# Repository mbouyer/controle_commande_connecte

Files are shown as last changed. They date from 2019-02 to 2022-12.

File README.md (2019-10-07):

# controle_commande_connecte
Une interface controle-commande pilotable par wifi

Le but du projet est de réaliser une interface de commande et contrôle
d'un équipement électrique, avec arrêt automatique lorsque une valeur de
consigne est atteinte, et surveillance à distance par wifi.

L'interface utilisateur est consituée de quatre bouttons poussoir (marche,
arrêt, définition de la consigne par +/-) et un écran LCD pour l'affichage.

Le capteur peut-être un capteur de température (résistance CTN), ou un
capteur de pression avec sortie différentielle.

Le matériel dispose également d'un transormateur de courant permettant de
mesurer l'intensité consomée par la charge. La charge est pilotée à travers
un relais.

* un microchip pic18f25q10,
  auquel sont connectés les capteurs de température et de courant,
  aunsi que les 4 interrupteurs et le relais
* un module ESP8266, qui commandera l'affichage et contient un module
  wifi.

Les deux microcontrolleurs communiquent par un bus i2c et une GPIO.

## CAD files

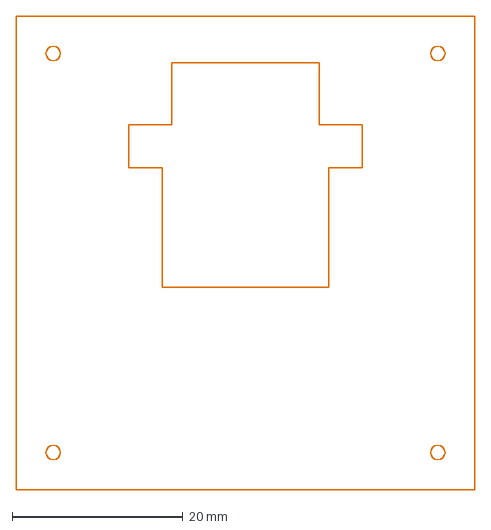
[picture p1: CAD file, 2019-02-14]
hardware/CAD/screen_bottom.dxf
53.7 x 55.4 mm

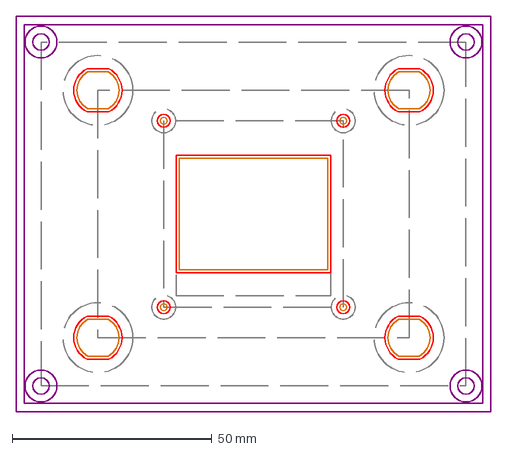
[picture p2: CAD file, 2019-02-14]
hardware/CAD/decoupe_couvercle.dxf
119.0 x 99.0 mm

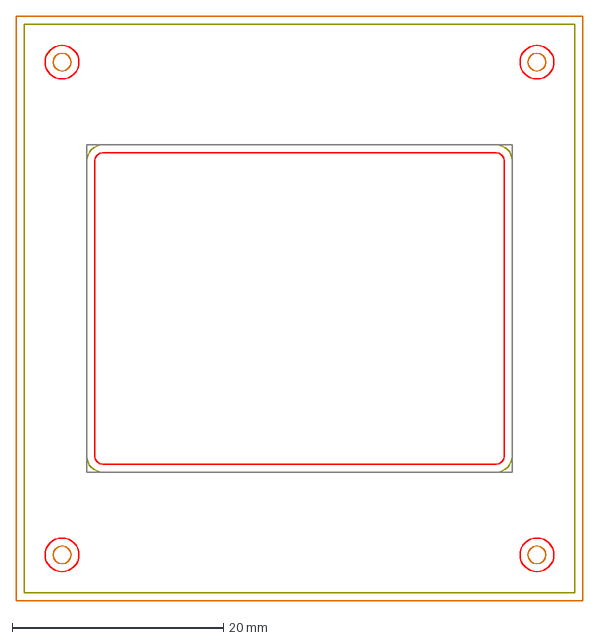
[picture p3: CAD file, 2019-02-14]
hardware/CAD/screen_top.dxf
53.7 x 55.4 mm

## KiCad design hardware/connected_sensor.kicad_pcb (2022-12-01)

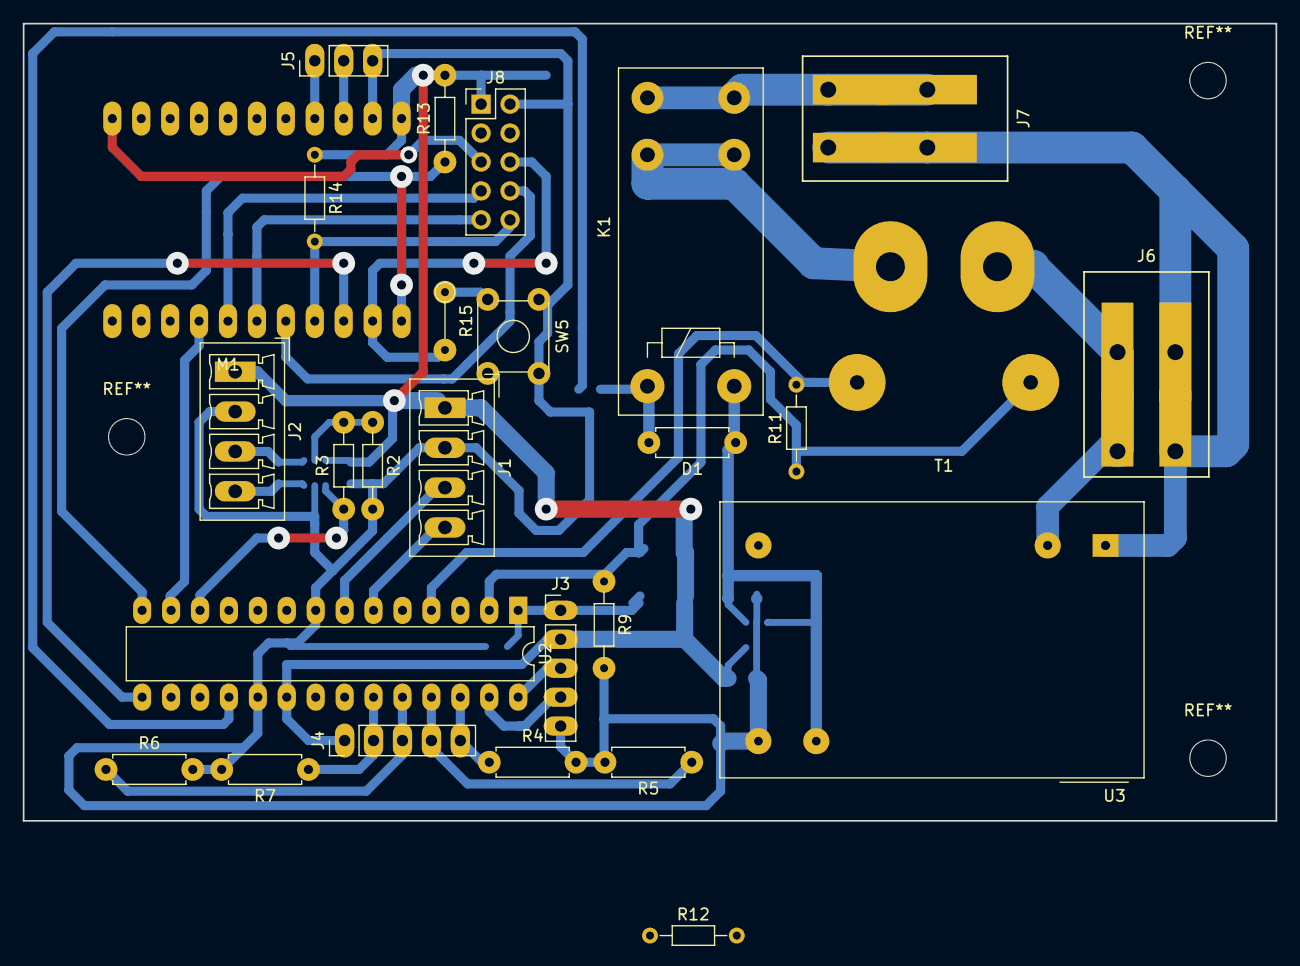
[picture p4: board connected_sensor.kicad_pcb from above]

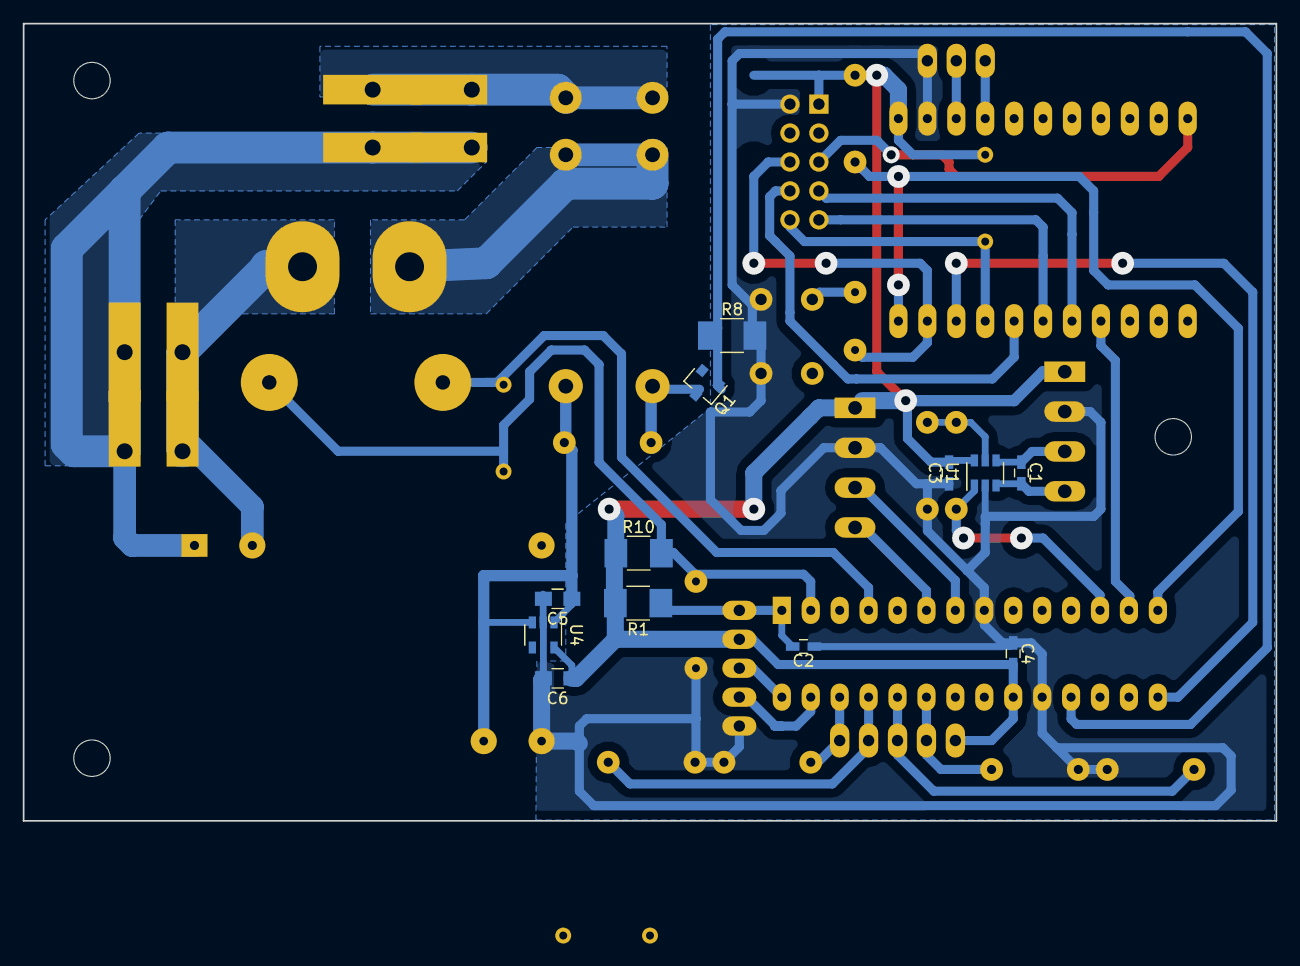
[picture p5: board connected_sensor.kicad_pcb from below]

Board: 2 copper layers, 110.0 x 70.0 mm, 39 parts (12 on the bottom side), 36 nets.

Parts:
C1, C2, C3, C4: 100nF; C_0603_HandSoldering
C5, C6: 1µ; C_0805_HandSoldering
D1: 1N4004; R_Axial_DIN0207_L6.3mm_D2.5mm_P7.62mm_Horizontal
J1, J2: Conn_01x04; PhoenixContact_MCV-G_04x3.50mm_Vertical
J3, J4: Conn_01x05; Pin_Header_Straight_1x05_Pitch2.54mm
J5: Conn_01x03; Pin_Header_Straight_1x03_Pitch2.54mm
J6: AC_IN; 1017491
J7: LOAD; 1017491
J8: UEXT; Pin_Header_Straight_2x05_Pitch2.54mm
K1: G2RL-1A-E 5DC; Relay_SPST_Schrack-RT1-16A-FormA_RM5mm
M1: ESP8266-DEV
Q1: ZXMN3A01FTA; SOT-23
R1, R8: 10K; R_1210_HandSoldering
R2: 5.6K; R_Axial_DIN0204_L3.6mm_D1.6mm_P7.62mm_Horizontal
R3: 100K; R_Axial_DIN0204_L3.6mm_D1.6mm_P7.62mm_Horizontal
R4, R5, R6, R7: 10K; R_Axial_DIN0207_L6.3mm_D2.5mm_P7.62mm_Horizontal
R9: 4.7k; R_Axial_DIN0204_L3.6mm_D1.6mm_P7.62mm_Horizontal
R10: 10k; R_1210_HandSoldering
R11: 18; R_Axial_DIN0204_L3.6mm_D1.6mm_P7.62mm_Horizontal
R12: NA; R_Axial_DIN0204_L3.6mm_D1.6mm_P7.62mm_Horizontal
R13: 2.2K; R_Axial_DIN0204_L3.6mm_D1.6mm_P7.62mm_Horizontal
R14: 47K; R_Axial_DIN0204_L3.6mm_D1.6mm_P7.62mm_Horizontal
R15: 220; R_Axial_DIN0204_L3.6mm_D1.6mm_P5.08mm_Vertical
SW5: SW_Push; SW_TH_Tactile_Omron_B3F-10xx
T1: Transformer_1P_1S; CSE187-LP
U1: MAX4460ESA; SOT-23-6
U2: PIC18F25Q10; DIP-28_W7.62mm_LongPads
U3: IRM-03-5; ACDC-Conv_THTMeanWell-IRM-03-XX
U4: MIC5504-3.3; SOT-23-5

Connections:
+3V3: C3.2, C4.2, C6.1, J1.1, J2.1, J3.2, J4.1, J8.1, M1.1, R1.2, R10.1, R12.2, R13.2, R14.1, U2.20, U4.5
+5V: C5.1, D1.1, K1.A2, U3.16, U4.1, U4.3
/AC1: J6.1, J7.1, U3.1
/AC2: J6.2, T1.1, U3.3
/ACL: J7.2, K1.14
/ACm: K1.11, T1.2
/BT1: J4.2, R7.1, U2.23
/BT2: J4.3, R6.1, U2.24
/BT3: J4.4, R5.1, U2.25
/BT4: J4.5, R4.1, U2.26
/CLK: J8.9, M1.17
/CS: J8.10, M1.19, R14.2
/C_D: J8.6, M1.21, R15.2
/LCD_RST: J8.5, M1.11
/MISO: J8.7, M1.16
/MOSI: J8.8, M1.18
/REL: Q1.1, R8.1, U2.18
/RXD: J5.1, M1.4
/TXD: J5.2, M1.3
CUR_REF: R9.1, R10.2, R11.1, T1.4, U2.2
CUR_SENSE: R11.2, T1.3, U2.4
DATA_READY: M1.15, U2.13
GND: C2.1, C3.1, C4.1, C5.2, C6.2, J1.2, J2.2, J3.5, J5.3, J8.2, M1.2, Q1.2, R2.2, R4.2, R5.2, R6.2, R7.2, R8.2, R9.2, SW5.1, SW5.2, U1.2, U2.8, U2.19, U3.14, U4.2
MCLR: C2.2, J3.1, R1.1, U2.1
unnamed: C1.1, J2.3, U1.6
unnamed: C1.2, J2.4, U1.3
unnamed: D1.2, K1.A1, Q1.3
unnamed: J1.3, U2.7
unnamed: J1.4, U2.6
unnamed: J3.3, U2.28
unnamed: J3.4, U2.27
unnamed: R2.1, R3.2
unnamed: R3.1, U1.1, U2.12
unnamed: R15.1, SW5.3
SCL: M1.22, R13.1, U2.14
SDA: M1.20, R12.1, U2.15

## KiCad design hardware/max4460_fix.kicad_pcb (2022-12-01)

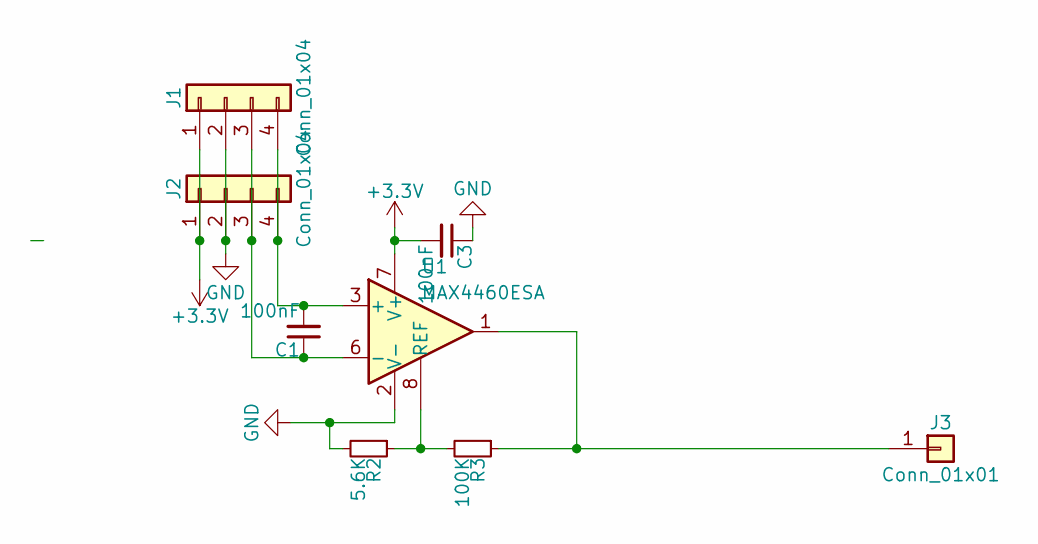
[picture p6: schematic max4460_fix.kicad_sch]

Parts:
C1, C3: 100nF; C_0603_HandSoldering
J1, J2: Conn_01x04; PhoenixContact_MCV-G_04x3.50mm_Vertical
J3: Conn_01x01; Pin_Header_Straight_1x01_Pitch2.54mm
R2: 5.6K; R_Axial_DIN0204_L3.6mm_D1.6mm_P7.62mm_Horizontal
R3: 100K; R_Axial_DIN0204_L3.6mm_D1.6mm_P7.62mm_Horizontal
U1: MAX4460ESA; SOIC-8_3.9x4.9mm_Pitch1.27mm

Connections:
+3V3: C3.2, J1.1, J2.1, U1.7 (V+)
GND: C3.1, J1.2, J2.2, R2.2, U1.2 (V-)
unnamed: C1.1, J1.3, J2.3, U1.6 (-)
unnamed: C1.2, J1.4, J2.4, U1.3 (+)
unnamed: J3.1, R3.1, U1.1
unnamed: R2.1, R3.2, U1.8 (REF)

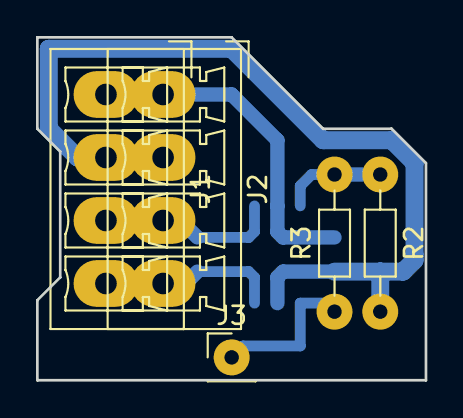
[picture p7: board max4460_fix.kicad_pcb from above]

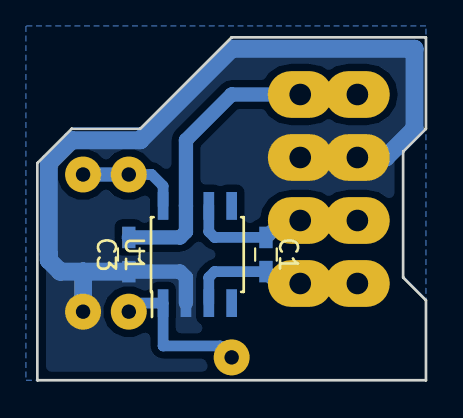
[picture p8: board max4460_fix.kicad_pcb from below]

Board: 2 copper layers, 21.6 x 19.0 mm, 8 parts (3 on the bottom side), 6 nets.

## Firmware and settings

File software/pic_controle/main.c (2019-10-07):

/*
 * Copyright (c) 2019 Manuel Bouyer
 *
 * All rights reserved.
 *
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
 * THIS SOFTWARE IS PROVIDED BY THE NETBSD FOUNDATION, INC. AND CONTRIBUTORS
 * ``AS IS'' AND ANY EXPRESS OR IMPLIED WARRANTIES, INCLUDING, BUT NOT LIMITED
 * TO, THE IMPLIED WARRANTIES OF MERCHANTABILITY AND FITNESS FOR A PARTICULAR
 * PURPOSE ARE DISCLAIMED.  IN NO EVENT SHALL THE FOUNDATION OR CONTRIBUTORS
 * BE LIABLE FOR ANY DIRECT, INDIRECT, INCIDENTAL, SPECIAL, EXEMPLARY, OR
 * CONSEQUENTIAL DAMAGES (INCLUDING, BUT NOT LIMITED TO, PROCUREMENT OF
 * SUBSTITUTE GOODS OR SERVICES; LOSS OF USE, DATA, OR PROFITS; OR BUSINESS
 * INTERRUPTION) HOWEVER CAUSED AND ON ANY THEORY OF LIABILITY, WHETHER IN
 * CONTRACT, STRICT LIABILITY, OR TORT (INCLUDING NEGLIGENCE OR OTHERWISE)
 * ARISING IN ANY WAY OUT OF THE USE OF THIS SOFTWARE, EVEN IF ADVISED OF THE
 * POSSIBILITY OF SUCH DAMAGE.
 */
#include <pic18fregs.h>
#include <stdio.h>
#include <math.h>
#include <my_serial.h>

#define PIC_VERSIONM 0x00
#define PIC_VERSIONm 0x01

extern char stack;
extern char stack_end;
#pragma stack 0x100 256
void _reset (void) __naked __interrupt 0;
void _startup (void) __naked;
static char counter_1hz;	
static volatile short counter_10hz;	
static volatile unsigned char softintrs;
#define INT_10HZ	 (unsigned char)0x01
#define INT_AD		 (unsigned char)0x02
#define INT_I2CFL	 (unsigned char)0x04

#define TIMER0_5MS 192 /* 48 without PLL */

#define TIMER2_10HZ 200

#define CLRWDT __asm__("clrwdt")
#define SLEEP __asm__("sleep")

static unsigned short ad_value;
static unsigned short ad_sense;
static unsigned short ad_ref;
static unsigned char cur_amps;
static unsigned char cur_press;

volatile unsigned char ad_state;
#define ADS_TIMERSTART	(unsigned char)0x01
#define ADS_CURR_REF	(unsigned char)0x02
#define ADS_CURR_SENSE	(unsigned char)0x04
#define ADS_PRESS	(unsigned char)0x08

/* ADC channels */
#define ADC_CUR_REF	0x00
#define ADC_CUR_SENSE	0x02
#define ADC_PRESS	0x11
#define ADC_GND		0x3c  /* 11 1100 */

/*
 * number of samples for current. With a 2Khz timer we'll need 40 samples
 * to capture a full AC cycle. Lets capture 2 cycles. As we do 2 measures
 * per samble this has to be 160
 */
#define ADC_NSMPLSAC	160

/*
 * number of samples for pressures. The ADC is 10 bits, the accumulator
 * is 16, so we can to up to 2^6 = 64 samples.
 */
#define ADC_NSMPLSP	64

/* I2C slave definitions */
#include "i2c.h"
unsigned char i2c_curreg; /* register pointer */
unsigned char i2c_reg_data; /* are we receiving reg pointer or data */
unsigned char i2c_flags; /* current flags */
unsigned char i2c_buttons; /* buttons status */

unsigned char i2cs_a, i2cs_r, i2cs_w, i2cs_s;

#define BUT_START	PORTBbits.RB2
#define BUT_STOP	PORTBbits.RB3
#define BUT_PLUS	PORTBbits.RB5
#define BUT_MINUS	PORTBbits.RB4
unsigned char but_start;
unsigned char but_stop;
unsigned char but_plus;
unsigned char but_minus;

#define OUT_MOTOR	LATCbits.LATC7
#define OUT_DATAR	LATCbits.LATC2

#define PRINTHEX(v) \
	{ \
		unsigned char c = (v); \
		if (c < 10) { \
			putchar('0' + c); \
		} else { \
			putchar(('a' - 10) + c ); \
		} \
	}

void
main(void) __naked
{
	unsigned char c;
	softintrs = 0;
	counter_1hz = 10;	

	/* everything is low priority by default */
	IPR1 = 0;
	IPR2 = 0;
	IPR3 = 0;
	IPR4 = 0;
	IPR5 = 0;
	IPR6 = 0;
	IPR7 = 0;
	INTCON = 0;
	INTCONbits.IPEN=1; /* enable interrupt priority */
	
	/* setup ADC and analog inputs */
	ANSELB=0x00; /* port B all digital */
	ANSELC = 0x01; //Set RC1 to analog, others digital
	TRISCbits.TRISC1 = 1;
	ANSELA = 0x05; //Set RA0 & RA2 to analog, others digital
	TRISAbits.TRISA0 = 1;
	TRISAbits.TRISA2 = 1;

	ADCON0 = 0;
	ADCON1 = 0;
	ADCON2 = 0x01; /* accumulate mode */
	ADCON0bits.ADFM = 1; /* right justify */
	ADCON0bits.ADON = 1;
	ADCLK=0x2e; /* Fosc / 64, 1us */
	ADACQ=10; /* 10us aquisition */
	ADREF=0;
	PIR1bits.ADIF = 0;
	PIE1bits.ADIE = 0;

	FVRCON = 0x82; /* fvr on, ADC output 2.048v */

	/* configure timer0 as free-running counter at 62.5Khz */
	T0CON0 = 0x10; /* 16bits, 1:1 postscaler */
	T0CON1 = 0x48; /* F0sc/4, 1:256 prescaler */
	PIR0bits.TMR0IF = 0;
	PIE0bits.TMR0IE = 0; /* no interrupt */
	T0CON0bits.T0EN = 1;
	
	USART_INIT(0);
	stdout = STREAM_USER; /* Use the macro PUTCHAR with printf */

#if TIMER2_10HZ == 100
	/* configure timer2 for 1Khz interrupt */
	T2CON = 0x64; /* postscaller 1/5, prescaler 1/64 */
	PR2 = 200; /* 1khz output */
#elif TIMER2_10HZ == 200
	/* configure timer2 for 1Khz interrupt */
	T2CON = 0x64; /* postscaller 1/5, prescaler 1/64 */
	PR2 = 100; /* 2khz output */
#else
#error "unknown TIMER2_10HZ"
#endif
	T2CLK = 0x02; /* Fosc */
	counter_10hz = TIMER2_10HZ;
	T2CONbits.TMR2ON = 1;
	PIR4bits.TMR2IF = 0;
	IPR4bits.TMR2IP = 1; /* high priority interrupt */
	PIE4bits.TMR2IE = 1;


	/* configure i2c */
	SSP1CON1 = 0x16; /* enable i2c in slave mode, 7 bit adress, CKP */
	SSP1CON2 = 0x01; /* SEN */
	SSP1CON3 = 0x00;
	SSP1STAT = 0x80;
	SSP1ADD = (I2C_ADDRESS << 1) & 0xfe;
	// SSP1MSK = 0xfe;
	SSP1MSK = 0x00;
	TRISCbits.TRISC3 = 1;
	TRISCbits.TRISC4 = 1;
	RC3PPS=0x0D;
	RC4PPS=0x0E;
	SSP1CON1bits.SSPEN=1;
	PIR3bits.SSP1IF = 0; // waiting to transmit/receive
	PIE3bits.SSP1IE = 1; // synchronous serial port interrupt enable
	i2c_curreg = i2c_flags = i2c_buttons = 0;
	but_start = but_stop = but_plus = but_minus = 0;
	i2cs_a = i2cs_r = i2cs_w = i2cs_s = 0;

	ad_state = ADS_PRESS;
	cur_amps = cur_press = 0;

	INTCONbits.GIE_GIEH=1;  /* enable high-priority interrupts */
	INTCONbits.PEIE_GIEL=1; /* enable low-priority interrrupts */

	OUT_MOTOR = 0; 
	TRISCbits.TRISC7 = 0;

	/* 4 buttons */
	TRISBbits.TRISB2 = 1;
	TRISBbits.TRISB3 = 1;
	TRISBbits.TRISB4 = 1;
	TRISBbits.TRISB5 = 1;

	OUT_DATAR = 0;
	TRISCbits.TRISC2 = 0; /* data_ready = out */

	WDTCON0bits.WDTPS = 0x0b; /* 2s watchdog */
	WDTCON1 = 0x17; /* MFINTOSC, always open */
	WDTCON0bits.SWDTEN = 1;
	CPUDOZEbits.IDLEN = 1;

	printf("ready %d.%d\n", PIC_VERSIONM, PIC_VERSIONm);

again:
	while (1) {
		CLRWDT;
		if (softintrs & INT_I2CFL) {
			softintrs &= ~INT_I2CFL;
			if (i2c_flags & I2C_FLAGS_MOTOR)
				OUT_MOTOR = 1;
			else
				OUT_MOTOR = 0;
		}
		if (softintrs & INT_AD) {
			if (ad_state & ADS_PRESS) {
				ad_value = (ADACCH << 8) | ADACCL;
				cur_press = (float)ad_value * 0.4531398 /
				    (float)ADC_NSMPLSP;
			} else {
				cur_amps = (float)ad_value * 0.61666667 /
				    (float)(ADC_NSMPLSAC / 2);
			}
			softintrs &= ~INT_AD;
		}
		if (softintrs & INT_10HZ) {
			softintrs &= ~INT_10HZ;
			/* cleanup hardware, in case something didn't complete */
			ADCON0bits.ADGO = 0;
			PIE1bits.ADIE = 0;
			ADCON2bits.ADACLR = 1;
			while (ADCON2bits.ADACLR)
				; /* wait */
			if ((ad_state & ADS_PRESS) != 0) {
				ad_value = 0;
				ADPCH = ADC_GND;
				ADPCH = ADC_CUR_REF;
				ADREF = 0x03; /* FVR */
				ad_state = ADS_CURR_REF;
			} else {
				ADPCH = ADC_GND;
				ADPCH = ADC_PRESS;
				ADREF = 0x00; /* Vcc */
				ad_state = ADS_PRESS;
			}
			PIR1bits.ADIF = 0;
			PIE1bits.ADIE = 1;
			ad_state |= ADS_TIMERSTART;
			counter_1hz--;
			if (counter_1hz == 0) {
				counter_1hz = 10;
				printf("I %d P %d B %d\n", cur_amps, cur_press, i2c_buttons);
				printf("i2c a %d r %d w %d s %d\n",
				    i2cs_a, i2cs_r, i2cs_w, i2cs_s);
				i2cs_a = i2cs_r = i2cs_w = i2cs_s = 0;
			}
		}
		if (but_start == 0xff)
			i2c_buttons |= I2C_BUTTONS_START;
		else if (but_start == 0)
			i2c_buttons &= ~I2C_BUTTONS_START;
		if (but_stop == 0xff)
			i2c_buttons |= I2C_BUTTONS_STOP;
		else if (but_stop == 0)
			i2c_buttons &= ~I2C_BUTTONS_STOP;
		if (but_plus == 0xff)
			i2c_buttons |= I2C_BUTTONS_PLUS;
		else if (but_plus == 0)
			i2c_buttons &= ~I2C_BUTTONS_PLUS;
		if (but_minus == 0xff)
			i2c_buttons |= I2C_BUTTONS_MINUS;
		else if (but_minus == 0)
			i2c_buttons &= ~I2C_BUTTONS_MINUS;

		if (RCREG1 == 'r')
			break;
		SLEEP;
	}

end:

	while ((c = getchar()) != 'r') {
		printf("got %c\n", c);
		goto again;
	}
	printf("returning\n");
	while (PIE3bits.TX1IE); /* wait for transmit to complete */
	

	INTCONbits.PEIE=0; /* disable peripheral interrupts */
	INTCONbits.GIE=0;  /* disable interrrupts */
}
unsigned int timer0_read() __naked
{
	/* return TMR0L | (TMR0H << 8), reading TMR0L first */
	__asm
	movf    _TMR0L, w
	movff   _TMR0H, _PRODL
	return
	__endasm;
}

/* Vectors */
void _reset (void) __naked __interrupt 0
{
	__asm__("goto __startup");
}

void _startup (void) __naked
{
  __asm
    // Initialize the stack pointer
    lfsr 1, _stack_end
    lfsr 2, _stack_end
    clrf _TBLPTRU, 0    // 1st silicon doesn't do this on POR

    __endasm ;

  /* Call the user's main routine */
  main();
  __asm__("reset");
}

/*
 * high priority interrupt. Split in 2 parts; one for the entry point
 * where we'll deal with timer0, then jump to another address
 * as we don't have enough space before the low priority vector
 */
void _irqh (void) __naked __shadowregs __interrupt 1
{
	__asm
	goto _irqh_timer2
	__endasm ;

}

void irqh_timer2(void) __naked
{
	/*
	 * no sdcc registers are automatically saved,
	 * so we have to be carefull with C code !
	 */
	__asm
	MOVFF   r0x00, POSTDEC1
	__endasm;
	PIR4bits.TMR2IF = 0;
	counter_10hz--;
	if (counter_10hz == 0) {
		counter_10hz = TIMER2_10HZ;
		softintrs |= INT_10HZ;
	}

	if (ADCON0bits.ADGO == 0 && (ad_state & ADS_TIMERSTART)) {
		ADCON0bits.ADGO = 1;
		ad_state &= ~ADS_TIMERSTART;
	}

	if (BUT_START) {
		if (but_start == 0x7f)
			OUT_DATAR = 1;
		but_start = but_start << 1;
		but_start |= (unsigned char)0x01;
	} else {
		if (but_start == 0x80)
			OUT_DATAR = 1;
		but_start = but_start << 1;
	}

	if (BUT_STOP) {
		if (but_stop == 0x7f)
			OUT_DATAR = 1;
		but_stop = but_stop << 1;
		but_stop |= (unsigned char)0x01;
	} else {
		if (but_stop == 0x80)
			OUT_DATAR = 1;
		but_stop = but_stop << 1;
	}

	if (BUT_PLUS) {
		if (but_plus == 0x7f)
			OUT_DATAR = 1;
		but_plus = but_plus << 1;
		but_plus |= (unsigned char)0x01;
	} else {
		if (but_plus == 0x80)
			OUT_DATAR = 1;
		but_plus = but_plus << 1;
	}

	if (BUT_MINUS) {
		if (but_minus == 0x7f)
			OUT_DATAR = 1;
		but_minus = but_minus << 1;
		but_minus |= (unsigned char)0x01;
	} else {
		if (but_minus == 0x80)
			OUT_DATAR = 1;
		but_minus = but_minus << 1;
	}

	__asm
	MOVFF   PREINC1, r0x00
	retfie 1
	nop
	__endasm;
}

void _irq (void) __interrupt 2 /* low priority */
{
	USART_INTR;

	if (PIR1bits.ADIF && PIE1bits.ADIE) {
		PIR1bits.ADIF = 0;
		if (ad_state & ADS_PRESS) {
			if (ADCNT == ADC_NSMPLSP) {
				softintrs |= INT_AD;
				PIE1bits.ADIE = 0;
			} else {
				ad_state |= ADS_TIMERSTART;
			}
		} else {
			if (ADCNT == ADC_NSMPLSAC) {
				softintrs |= INT_AD;
				PIE1bits.ADIE = 0;
			} else {
				if (ad_state & ADS_CURR_REF) {
					ad_ref = (ADRESH << 8) | ADRESL;
					ad_state = ADS_CURR_SENSE;
					ADPCH = ADC_GND;
					ADPCH = ADC_CUR_SENSE;
					ADCON0bits.ADGO = 1;
				} else {
					ad_sense = (ADRESH << 8) | ADRESL;
					if (ad_sense < ad_ref) {
						ad_value+= (ad_ref - ad_sense);
					} else {
						ad_value+= (ad_sense - ad_ref);
					}
					ad_state = ADS_CURR_REF;
					ADPCH = ADC_GND;
					ADPCH = ADC_CUR_REF;
					ad_state |= ADS_TIMERSTART;
				}
			}
		}
	}

	if (PIR3bits.SSP1IF == 1) {
		PIR3bits.SSP1IF = 0;
		if (!SSP1CON3bits.ACKTIM) {
			if ((SSP1CON1bits.SSPOV) || (SSP1CON1bits.WCOL)) {
				printf("i2c o %d\n", SSP1CON1);
				SSP1CON1bits.SSPOV = 0;
				SSP1CON1bits.WCOL = 0;
				SSP1CON1bits.CKP = 1;
				(void)SSP1BUF; /* clear buffer */
			}

			if (!SSP1STATbits.D_NOT_A && SSP1STATbits.BF) {
				// printf("i2c a %d\n", SSP1BUF);
				i2cs_a++;
				(void)SSP1BUF;
				i2c_reg_data = 1;
			}  else if (!SSP1STATbits.R_NOT_W && SSP1STATbits.BF) {
				if (i2c_reg_data) {
					i2c_curreg = SSP1BUF;
					//printf("i2c s %d\n", i2c_curreg);
					i2c_reg_data = 0;
					i2cs_s++;
				} else {
					// printf("i2c w %d\n", i2c_curreg);
					i2cs_w++;
					switch(i2c_curreg) {
					case I2C_R_FLAGS:
						i2c_flags = SSP1BUF;
						softintrs |= INT_I2CFL;
						break;
					default:
						(void)SSP1BUF;
						break;
					}
					i2c_curreg++;
				}
			}

			if (SSP1STATbits.R_NOT_W) {
				(void)SSP1BUF;
				// printf("i2c r %d\n", i2c_curreg);
				i2cs_r++;
				switch(i2c_curreg) {
				case I2C_R_VERSM:
					SSP1BUF = PIC_VERSIONM;
					break;
				case I2C_R_VERSm:
					SSP1BUF = PIC_VERSIONm;
					break;
				case I2C_R_FLAGS:
					SSP1BUF = i2c_flags;
					break;
				case I2C_R_BUTTONS:
					SSP1BUF = i2c_buttons;
					OUT_DATAR = 0;
					break;
				case I2C_R_AMP:
					SSP1BUF = cur_amps;
					break;
				case I2C_R_PRES:
					SSP1BUF = cur_press;
					break;
				default:
					SSP1BUF = 0;
					break;
				}
				i2c_curreg++;
			}
		}
		SSP1CON1bits.CKP = 1;
	}
}

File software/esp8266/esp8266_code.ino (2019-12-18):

/*
 * Copyright (c) 2019 Manuel BOUYER
 * All rights reserved.
 *
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
 * THIS SOFTWARE IS PROVIDED BY THE NETBSD FOUNDATION, INC. AND CONTRIBUTORS
 * ``AS IS'' AND ANY EXPRESS OR IMPLIED WARRANTIES, INCLUDING, BUT NOT LIMITED
 * TO, THE IMPLIED WARRANTIES OF MERCHANTABILITY AND FITNESS FOR A PARTICULAR
 * PURPOSE ARE DISCLAIMED.  IN NO EVENT SHALL THE FOUNDATION OR CONTRIBUTORS
 * BE LIABLE FOR ANY DIRECT, INDIRECT, INCIDENTAL, SPECIAL, EXEMPLARY, OR
 * CONSEQUENTIAL DAMAGES (INCLUDING, BUT NOT LIMITED TO, PROCUREMENT OF
 * SUBSTITUTE GOODS OR SERVICES; LOSS OF USE, DATA, OR PROFITS; OR BUSINESS
 * INTERRUPTION) HOWEVER CAUSED AND ON ANY THEORY OF LIABILITY, WHETHER IN
 * CONTRACT, STRICT LIABILITY, OR TORT (INCLUDING NEGLIGENCE OR OTHERWISE)
 * ARISING IN ANY WAY OUT OF THE USE OF THIS SOFTWARE, EVEN IF ADVISED OF THE
 * POSSIBILITY OF SUCH DAMAGE.
 */

#include <ESP8266WiFi.h>
#include <ESPAsyncTCP.h>
#include <ESPAsyncWebServer.h>
#include <DNSServer.h>
#include <LCD_3310.h>
#include <Wire.h>
#include <FS.h>
#include <ESP_EEPROM.h>
#include "../pic_controle/i2c.h"
#include "wifi_params.h"

#define SDA_PIN 2
#define SCL_PIN 4
#define DATA_READY  16

#define VERSIONM 0
#define VERSIONm 3

#define EEPROM_VERSION 0x01
#define EEPROM_SIZE 16 // overkill but minimum is 16

// #define NO_PIC 1 // emulation mode

#ifdef NO_PIC
unsigned long no_pic_emultime = 0;
#define NO_PIC_UPDATE 20000 // 20s
float no_pic_press;
#endif

unsigned short runtime;
unsigned int milliruntime;
unsigned long runtime_last;

#define DISP_UPDATE 500 //ms
unsigned long disp_up_last = 0;

// motor status
bool motor_on = 0;

// sensors
unsigned char press;
unsigned char target_press = 115;
unsigned int current;

// ETA compute
#define ETA_SAMPLES 5
unsigned char previous_press[ETA_SAMPLES];
unsigned long eta_millis;
short etatime;


// buttons
unsigned char buttons_state;
unsigned long plusminus_timer;
#define PLUSMINUS_SLOW 1000 // 1s
#define PLUSMINUS_FAST 3000 // 3s

// Access Point

const IPAddress local_IP(192,168,1,1);
const IPAddress subnet(255,255,255,0);

AsyncWebServer server(80);
DNSServer dnsServer;

static int
i2c_write(char reg, char value)
{
	Wire.beginTransmission(I2C_ADDRESS);
	Wire.write(reg);
	Wire.write(value);
	return Wire.endTransmission();
	// 0:success
	// 1:data too long to fit in transmit buffer
	// 2:received NACK on transmit of address
	// 3:received NACK on transmit of data
	// 4:other error
}

static int
i2c_read(char reg, char *v, char count)
{
	int ret;
	int i;

	Wire.beginTransmission(I2C_ADDRESS);
	Wire.write(reg);
	ret = Wire.endTransmission();
	if (ret != 0)
		return -ret;

	Wire.requestFrom(I2C_ADDRESS, count);
	ret = Wire.available();
	for (i = 0; i < ret; i++) {
		v[i] = Wire.read();
	}
	return ret;
}

static void
do_motor(bool m)
{
	unsigned char flags = 0;
	int ret;
	char buf[17];

	motor_on = m;
	if (motor_on)
		flags |= I2C_FLAGS_MOTOR;

#ifndef NO_PIC
	while ((ret = i2c_write(I2C_W_FLAGS, flags)) != 0) {
		LCDClear();
		sprintf(buf, "write pic %d", ret);
		Serial.println(buf);
		LCDStr(5, 2, buf, 0, 5); 
		delay(500);
	}
#endif
}

static void
time2str(char *buf, int time) {
	sprintf(buf, "%dh%02d", time / 60, time % 60);
}

static void
etatime2str(char *buf) {
	if (etatime == 0) {
	    sprintf(buf, "----");
	} else if (etatime >= 60 * 10) {
	    sprintf(buf, "++++");
	} else {
	    time2str(buf, etatime);
	}
}


static String
toStringIp(IPAddress ip) {
	String res = "";
	for (int i = 0; i < 3; i++) {
		res += String((ip >> (8 * i)) & 0xFF) + ".";
	}
	res += String(((ip >> 8 * 3)) & 0xFF);
	return res;
}

static String
getContentType(String filename) {
	if(filename.endsWith(".html")) return "text/html";
	else if(filename.endsWith(".css")) return "text/css";
	else if(filename.endsWith(".js")) return "application/javascript";
	else if(filename.endsWith(".png")) return "image/png";
	else if(filename.endsWith(".gif")) return "image/gif";
	else if(filename.endsWith(".jpg")) return "image/jpeg";
	else if(filename.endsWith(".ico")) return "image/x-icon";
	else if(filename.endsWith(".xml")) return "text/xml";
	return "text/plain";
}



static void
handleNotFound(AsyncWebServerRequest *request)
{
	String filename = "/http" + request->url();

	if(SPIFFS.exists(filename)) {
		request->send(SPIFFS, filename, getContentType(filename));
		return;
	}
	Serial.print("request for http://");
	Serial.print(request->host());
	Serial.println(request->url());
	request->redirect(String("http://") + toStringIp(local_IP));
}

String
fill_html(const String& var)
{
	char buf[10];
	if(var == "PRESS") {
		return String(press*2);
	} else if (var == "CONS") {
		return String(target_press*2);
	} else if (var == "AMPS") {
		sprintf(buf, "%d.%d", current / 10, current % 10);
		return String(buf);
	}
	Serial.print("unknown HTML tag ");
	Serial.println(var);
	return String("");
}


void
setup() {
	char v[2];
	char buf[80];
	int ret, i;
	char ee_version;

	delay(1000);
	Serial.begin(57600);
	Serial.println();
	Serial.println("Configuring access point...");
	WiFi.softAP(WIFI_SSID, WIFI_PASS, 1, false, 8);
	WiFi.softAPConfig(local_IP, local_IP, subnet);

	Serial.print("AP IP address: ");
	Serial.println(local_IP);

	/* Setup the DNS server redirecting all the domains to the apIP */
	dnsServer.setTTL(300);
	dnsServer.setErrorReplyCode(DNSReplyCode::NoError);
	dnsServer.start(53, "*", local_IP);


	Wire.begin(SDA_PIN,SCL_PIN);
	Wire.setClock(100000); // clock 100KHz
	pinMode(16, INPUT);  // Data_ready

	LCDInit();
	LCDContrast (0x60);
	LCDClear();
	LCDUpdate();

	sprintf(buf, "aperosafe %d.%d", VERSIONM, VERSIONm);
	Serial.println("wait on PIC");
	LCDStr(5, 2, "wait on pic", 0, 5);
#ifndef NO_PIC
	while ((ret = i2c_read(I2C_R_VERSM, v, 2)) != 2) {
		sprintf(buf, "wait on pic %d", ret);
		Serial.println(buf);
		delay(500);
	}
	if (v[0] != PIC_VERSIONM) {
		sprintf(buf, "wrong pic %d.%d", v[0], v[1]);
		LCDStr(5, 2, buf, 0, 5); 
		Serial.println(buf);
		while (1) {
			delay(500);
		}
	}
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

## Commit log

2018-12-12 Premier import, le matériel devrait être définitif
    [connected_sensor.kicad_pcb, connected_sensor.sch]
2019-01-10 max4460esa est SIOC8 et pas SOT-6; ajout d'un petit PCB d'adaptation. Il se soude sur les broches résistances et connecteur (J2) du PCB principal.
    [max4460_fix.kicad_pcb, max4460_fix.sch]
2019-02-14 Ajout des fichiers CAO pour les découpes et support écran.
    [decoupe_couvercle.dxf, screen_bottom.dxf, screen_top.dxf]
2019-10-07 L'ecran necessite 2 GPIOs en plus du SPI. Re-route 2 GPIOs de l'ESP vers le connecteur ecran.
    [connected_sensor.kicad_pcb, connected_sensor.sch]
2019-10-07 Version initiale du logiciel pour les microcontrolleurs.
2019-10-17 Serve any file present in SPIFFS, with content-type based on extention. Provide sensor values as plain text. Add a wheel icon on the web page, and make it spin when the device is on. Make the css res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
2019-11-19 Add ETA and power on counter. better wifi display
2019-11-27 Ops, fix sign for ETA computaion
    [esp8266_code.ino]
2019-12-18 Implement a "NO_PIC" emulation mode, which allows testing display and some computations with a standalone esp8266 module. Fix some signed/unsigned and overflow issues with ETA
    [esp8266_code.ino]
2019-12-18 Properly clear LCD also when automatically stopping motor
2022-12-01 Convert to kicad 6.x
    [connected_sensor.kicad_pcb, connected_sensor.kicad_sch, max4460_fix.kicad_pcb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]
2022-12-02 Note P/N for current transformer
    [connected_sensor.kicad_sch]
2022-12-12 Add surge protections on current sensor
    [connected_sensor.kicad_sch]
